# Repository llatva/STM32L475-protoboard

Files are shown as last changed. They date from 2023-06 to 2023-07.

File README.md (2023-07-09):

## STM32L475 protoboard

Development board for STM32L475 (4-layer board). Includes header for W5500 Ethernet module (SPI bus).

JP2 solder jumper needs to be short-circuited to enable USB VBUS detection (not needed if powered only from microUSB connector). Solder jumper needs to be short-circuited to enable USR1 LED. R8 is NOT to be mounted (USB data line pull-up is not used for this MCU type). Fuse pads are for polyswitch fuses. SMD capacitor pads are for A/D LPF (MCU pins have multiple functions).

Boot selection pin (BOOT0) next to the programming connector should be in normal operation shorted to GND (jumper). This means booting from FLASH.

Connector pinouts are documented on the bottom side of the board (programming interface, SPI interface).

See also the daughterboard, in the subdirectory "STM32daughter".

Designed by Lasse OH3HZB 2023

This work is licensed under a [Creative Commons Attribution-NonCommercial 4.0 International License (CC BY-NC 4.0)](https://creativecommons.org/licenses/by-nc/4.0/).

### RevA ERRATA

* Silkscreen: BOTTOM silkscreen, Ethernet connector's pin next to 3V3 is VDC, not "NC". Actual wiring is correct.

### 3D

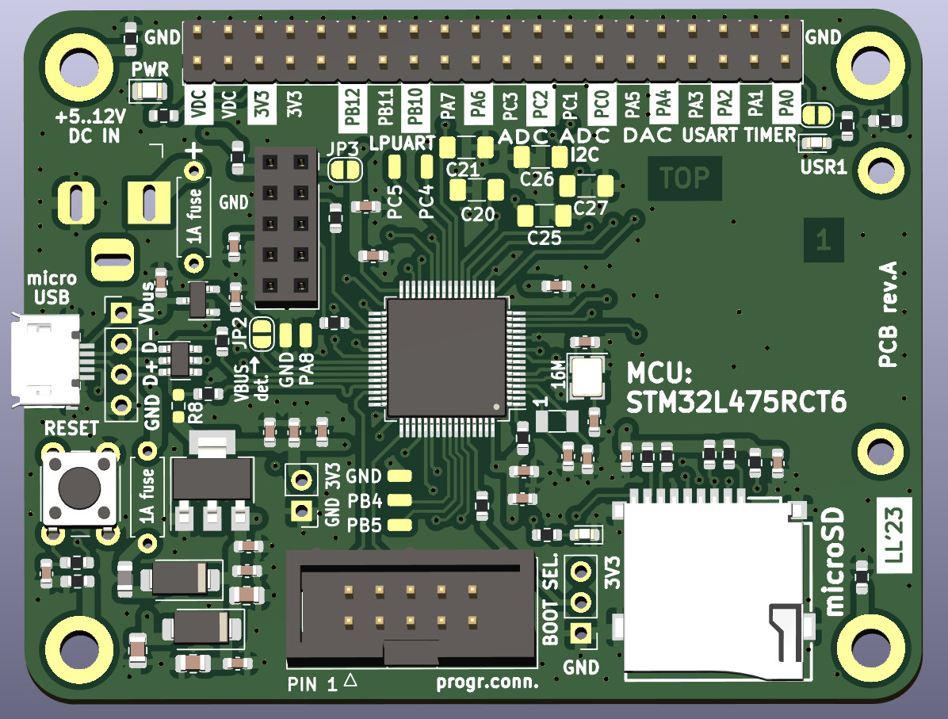
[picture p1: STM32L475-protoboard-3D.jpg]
3d


### Photo

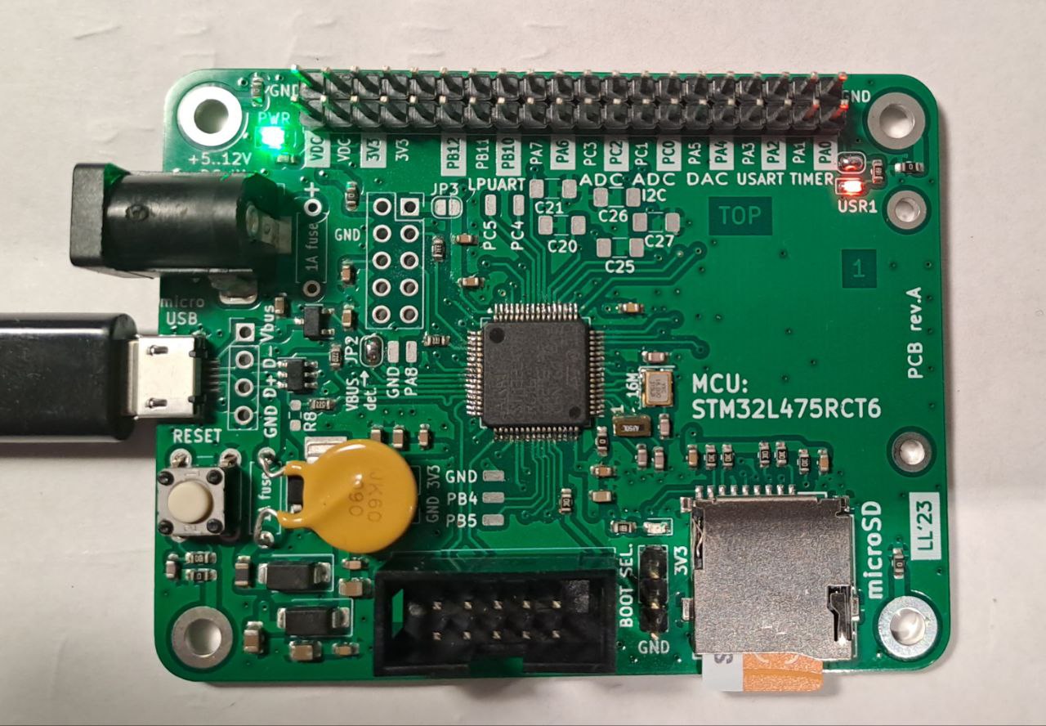
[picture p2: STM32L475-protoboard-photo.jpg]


### Schematic

Open with KiCAD (v.7+) or use [this PDF](STM32L475-protoboard.pdf).

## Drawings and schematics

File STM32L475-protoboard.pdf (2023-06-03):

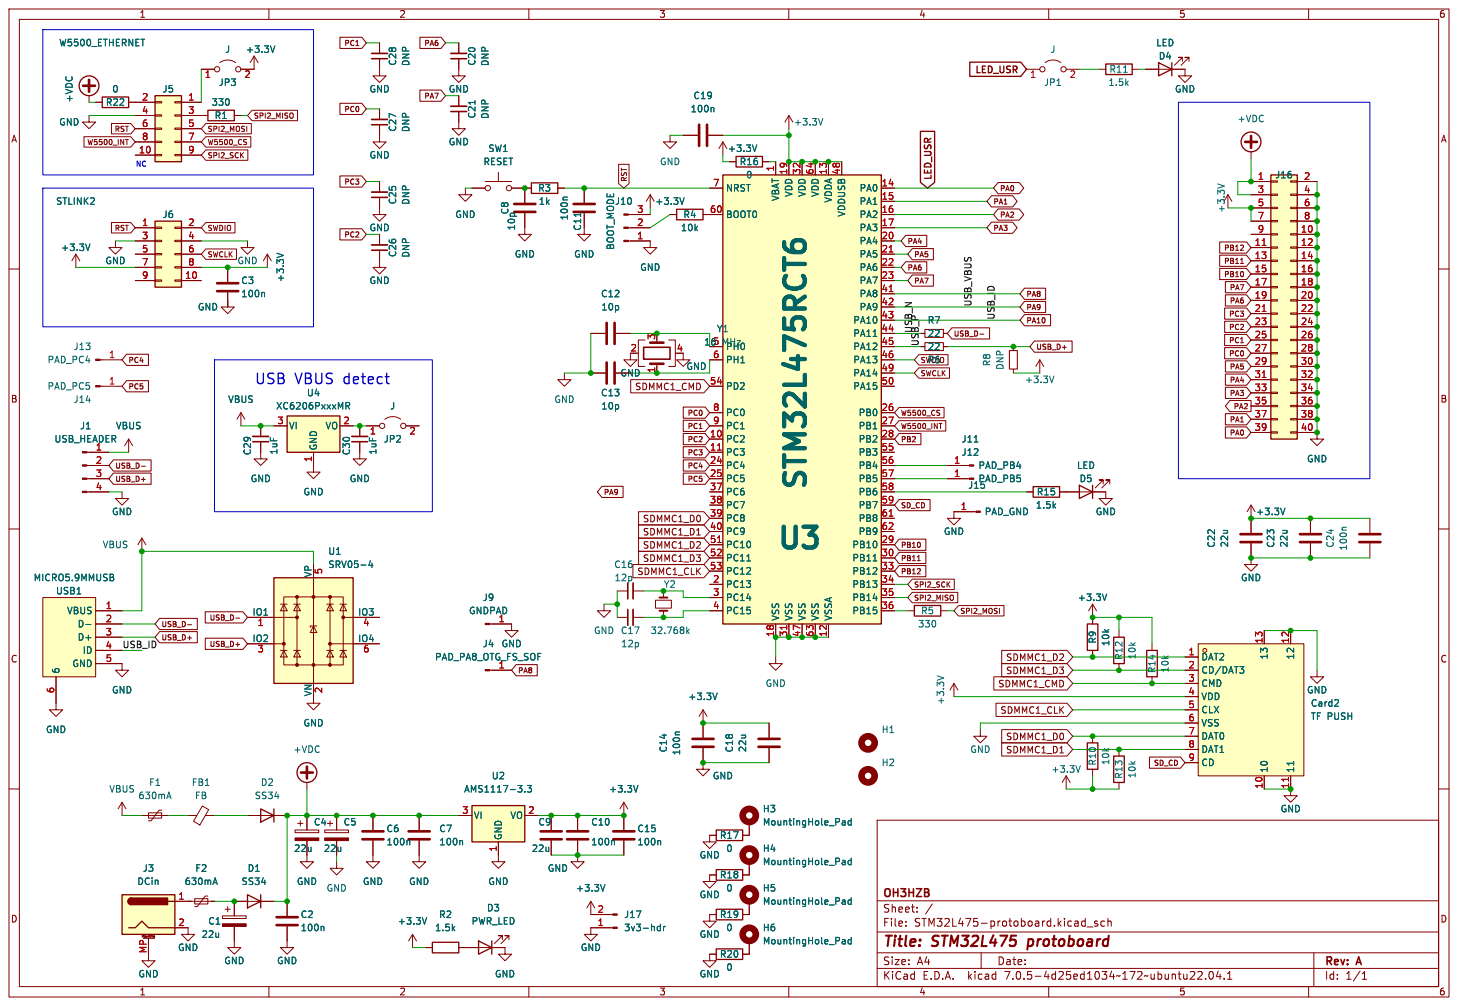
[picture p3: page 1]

1 PC2 10 PC3 11 VSSA 12 VDDA 13 PA0 14 PA1 15 PA2 16 PA3 17 VSS 18 VDD 19 PC13 2 PA4 20 PA5 21 PA6 22 PA7 23 PC4 24 PC5 25 PB0 26 PB1 27 PB2 28 PB10 29 PC14 3 PB11 30 VSS 31 VDD 32 PB12 33 PB13 34 PB14 35 PB15 36 PC6 37 PC7 38 PC8 39 PC15 4 PC9 40 PA8 41 PA9 42 PA10 43 PA11 44 PA12 45 PA13 46 VSS 47 VDDUSB 48 PA14 49 PH0 5 PA15 50 PC10 51 PC11 52 PC12 53 PD2 54 PB3 55 PB4 56 PB5 57 PB6 58 PB7 59 PH1 6 BOOT0 60 PB8 61 PB9 62 VSS 63 VDD 64 NRST 7 PC0 8 PC1 9 U3STM32L475RCT6 C13

1 PC2 10 PC3 11 VSSA 12 VDDA 13 PA0 14 PA1 15 PA2 16 PA3 17 VSS 18 VDD 19 PC13 2 PA4 20 PA5 21 PA6 22 PA7 23 PC4 24 PC5 25 PB0 26 PB1 27 PB2 28 PB10 29 PC14 3 PB11 30 VSS 31 VDD 32 PB12 33 PB13 34 PB14 35 PB15 36 PC6 37 PC7 38 PC8 39 PC15 4 PC9 40 PA8 41 PA9 42 PA10 43 PA11 44 PA12 45 PA13 46 VSS 47 VDDUSB 48 PA14 49 PH0 5 PA15 50 PC10 51 PC11 52 PC12 53 PD2 54 PB3 55 PB4 56 PB5 57 PB6 58 PB7 59 PH1 6 BOOT0 60 PB8 61 PB9 62 VSS 63 VDD 64 NRST 7 PC0 8 PC1 9 C13

FB1 FB VBUS GND GND

1 VO 2 VI 3 U2 AMS1117-3.3 GND GND

1 VO 2 VI 3 GND GND

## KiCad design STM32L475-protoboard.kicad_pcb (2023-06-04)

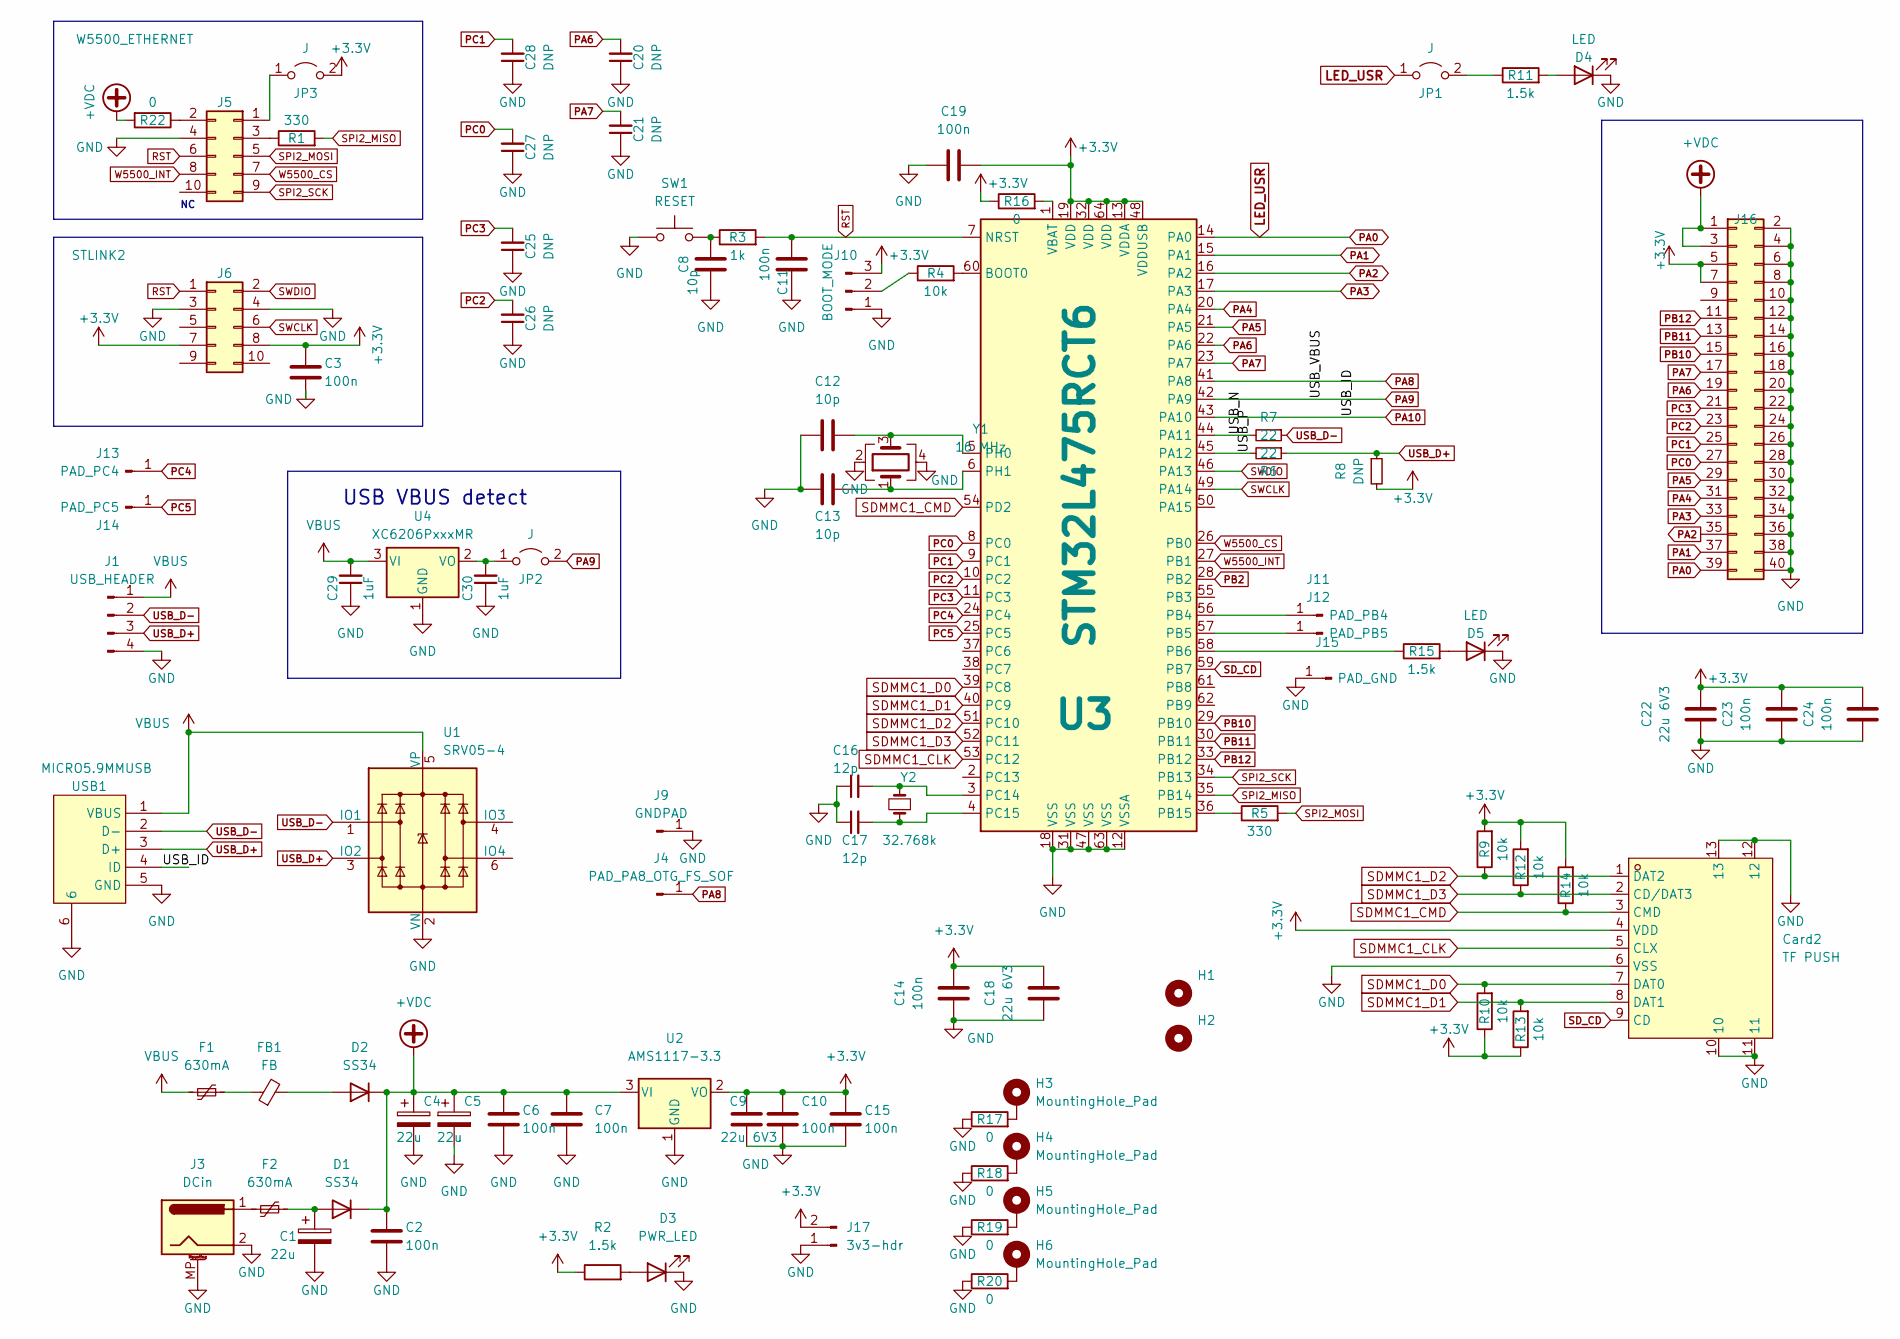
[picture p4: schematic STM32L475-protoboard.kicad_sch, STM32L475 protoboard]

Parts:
C1, C4, C5: 22u; C_0805_2012Metric; LCSC C45783
C2, C3, C6, C7, C10, C11, C14, C15, C19, C23, C24: 100n; C_0603_1608Metric; LCSC C14663
C8, C12, C13: 10p; C_0603_1608Metric; LCSC C1634
C9, C18, C22: 22u 6V3; C_0603_1608Metric; LCSC C59461
C16, C17: 12p; C_0603_1608Metric; LCSC C38523
C20, C21, C25, C26, C27, C28: DNP; C_1206_3216Metric_Pad1.33x1.80mm_HandSolder
C29, C30: 1uF; C_0603_1608Metric; LCSC C15849
Card2: TF PUSH; TF-SMD_TF-PUSH; LCSC Part C393941
D1, D2: SS34; D_SMA; LCSC C8678
D3: PWR_LED; LED_0805_2012Metric; LCSC C2297
D4, D5: LED; LED_0603_1608Metric; LCSC C2286
F1, F2: 630mA; R_Axial_DIN0207_L6.3mm_D2.5mm_P7.62mm_Horizontal
FB1: FB; L_0805_2012Metric; LCSC C1015
H1, H2: MountingHole_Pad; MountingHole_2.2mm_M2_DIN965_Pad_TopBottom
H3, H4, H5, H6: MountingHole_Pad; MountingHole_3.2mm_M3_DIN965_Pad_TopBottom
J1: USB_HEADER; PinHeader_1x04_P2.54mm_Vertical
J3: DCin; BarrelJack_Horizontal
J4: PAD_PA8_OTG_FS_SOF; SolderWirePad_1x01_SMD_1x2mm
J5: W5500_ETHERNET; PinSocket_2x05_P2.54mm_Vertical
J6: STLINK2; IDC-Header_2x05_P2.54mm_Vertical
J9: GNDPAD; SolderWirePad_1x01_SMD_1x2mm
J10: BOOT_MODE; PinHeader_1x03_P2.54mm_Vertical
J11: PAD_PB4; SolderWirePad_1x01_SMD_1x2mm
J12: PAD_PB5; SolderWirePad_1x01_SMD_1x2mm
J13: PAD_PC4; SolderWirePad_1x01_SMD_1x2mm
J14: PAD_PC5; SolderWirePad_1x01_SMD_1x2mm
J15: PAD_GND; SolderWirePad_1x01_SMD_1x2mm
J16: Conn_02x20_Odd_Even; PinHeader_2x20_P2.54mm_Vertical
J17: 3v3-hdr; PinHeader_1x02_P2.54mm_Vertical
JP1, JP2, JP3: J; SolderJumper-2_P1.3mm_Open_RoundedPad1.0x1.5mm
R1, R5: 330; R_0603_1608Metric; LCSC C23138
R2, R11, R15: 1.5k; R_0603_1608Metric; LCSC C22843
R3: 1k; R_0603_1608Metric_Pad0.98x0.95mm_HandSolder; LCSC C21190
R4, R9, R10, R12, R13, R14: 10k; R_0603_1608Metric; LCSC C25804
R6, R7: 22; R_0603_1608Metric; LCSC C23345
R8: DNP; R_0603_1608Metric_Pad0.98x0.95mm_HandSolder
R16, R17, R18, R19, R20, R22: 0; R_0603_1608Metric_Pad0.98x0.95mm_HandSolder; LCSC C21189
SW1: RESET; SW_PUSH_6mm_H4.3mm
U1: SRV05-4; SOT-23-6; LCSC C85364
U2: AMS1117-3.3; SOT-223-3_TabPin2; LCSC C6186
U3: STM32L475RCT6; LQFP-64_10x10mm_P0.5mm
U4: XC6206PxxxMR; SOT-23-3; LCSC C5446
USB1: MICRO5.9MMUSB; MICRO-USB-SMD_5P-P0.65-H-F_MICRO5.9MMUSB; LCSC C393940
Y1: 16 MHz; Crystal_SMD_3225-4Pin_3.2x2.5mm; LCSC C13738
Y2: 32.768k; Crystal_SMD_3215-2Pin_3.2x1.5mm; LCSC C32346

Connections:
+3V3: C3.1, C9.1, C10.1, C14.2, C15.1, C18.2, C19.2, C22.2, C23.2, C24.2, Card2.4 (VDD), J6.7, J6.8, J10.3, J16.5, J16.7, J17.2, JP3.2 (B), R2.1, R8.2, R9.2, R10.1, R12.2, R13.1, R14.2, R16.1, U2.2 (VO), U3.13 (VDDA), U3.19 (VDD), U3.32 (VDD), U3.48 (VDDUSB), U3.64 (VDD)
+VDC: C2.1, C4.1, C5.1, C6.1, C7.1, D1.1 (K), D2.1 (K), J16.1, J16.3, R22.2, U2.3 (VI)
/USB_N: R6.2, U3.44 (PA11)
/USB_P: R7.2, U3.45 (PA12)
GND: C1.2, C2.2, C3.2, C4.2, C5.2, C6.2, C7.2, C8.2, C9.2, C10.2, C11.1, C12.1, C13.2, C14.1, C15.2, C16.1, C17.1, C18.1, C19.1, C20.1, C21.1, C22.1, C23.1, C24.1, C25.1, C26.1, C27.1, C28.1, C29.1, C30.1, Card2.6 (VSS), Card2.10, Card2.11, Card2.12, Card2.13, D3.1 (K), D4.1 (K), D5.1 (K), J1.4, J3.2, J3.MP (MountPin), J5.4, J6.3, J6.4, J9.1, J10.1, J15.1, J16.2, J16.4, J16.6, J16.8, J16.10, J16.12, J16.14, J16.16, J16.18, J16.20, J16.22, J16.24, J16.26, J16.28, J16.30, J16.32, J16.34, J16.36, J16.38, J16.40, J17.1, R17.1, R18.1, R19.1, R20.1, SW1.1, U1.2 (VN), U2.1 (GND), U3.12 (VSSA), U3.18 (VSS), U3.31 (VSS), U3.47 (VSS), U3.63 (VSS), U4.1 (GND), USB1.5 (GND), USB1.6, Y1.2, Y1.4
LED_USR: J16.39, JP1.1 (A), U3.14 (PA0)
unnamed: C8.1, R3.1, SW1.2
unnamed: C1.1, D1.2 (A), F2.1
unnamed: D2.2 (A), FB1.2
unnamed: D3.2 (A), R2.2
unnamed: D4.2 (A), R11.2
unnamed: D5.2 (A), R15.2
unnamed: F1.1, FB1.1
unnamed: F2.2, J3.1
unnamed: H3.1, R17.2
unnamed: H4.1, R18.2
unnamed: H5.1, R19.2
unnamed: H6.1, R20.2
unnamed: J5.1, JP3.1 (A)
unnamed: J5.2, R22.1
unnamed: J5.3, R1.1
unnamed: J10.2, R4.1
unnamed: J11.1, U3.56 (PB4)
unnamed: J12.1, U3.57 (PB5)
unnamed: JP1.2 (B), R11.1
unnamed: C30.2, JP2.1 (A), U4.2 (VO)
unnamed: R4.2, U3.60 (BOOT0)
unnamed: R15.1, U3.58 (PB6)
unnamed: R5.1, U3.36 (PB15)
unnamed: C16.2, U3.3 (PC14), Y2.2
unnamed: C17.2, U3.4 (PC15), Y2.1
unnamed: C12.2, U3.5 (PH0), Y1.3
unnamed: C13.1, U3.6 (PH1), Y1.1
unnamed: R16.2, U3.1 (VBAT)
PA1: J16.37, U3.15 (PA1)
PA2: J16.35, U3.16 (PA2)
PA3: J16.33, U3.17 (PA3)
PA4: J16.31, U3.20 (PA4)
PA5: J16.29, U3.21 (PA5)
PA6: C20.2, J16.19, U3.22 (PA6)
PA7: C21.2, J16.17, U3.23 (PA7)
PA8: J4.1, U3.41 (PA8)
PA9: JP2.2 (B), U3.42 (PA9)
PA10: U3.43 (PA10), USB1.4 (ID)
PB2: U3.28 (PB2)
PB10: J16.15, U3.29 (PB10)
PB11: J16.13, U3.30 (PB11)
PB12: J16.11, U3.33 (PB12)
PC0: C27.2, J16.27, U3.8 (PC0)
PC1: C28.2, J16.25, U3.9 (PC1)
PC2: C26.2, J16.23, U3.10 (PC2)
PC3: C25.2, J16.21, U3.11 (PC3)
PC4: J13.1, U3.24 (PC4)
PC5: J14.1, U3.25 (PC5)
RST: C11.2, J5.6, J6.1, R3.2, U3.7 (NRST)
SDMMC1_CLK: Card2.5 (CLX), U3.53 (PC12)
SDMMC1_CMD: Card2.3 (CMD), R14.1, U3.54 (PD2)
SDMMC1_D0: Card2.7 (DAT0), R10.2, U3.39 (PC8)
SDMMC1_D1: Card2.8 (DAT1), R13.2, U3.40 (PC9)
SDMMC1_D2: Card2.1 (DAT2), R9.1, U3.51 (PC10)
SDMMC1_D3: Card2.2 (CD/DAT3), R12.1, U3.52 (PC11)
SD_CD: Card2.9 (CD), U3.59 (PB7)
SPI2_MISO: R1.2, U3.35 (PB14)
SPI2_MOSI: J5.5, R5.2
SPI2_SCK: J5.9, U3.34 (PB13)
SWCLK: J6.6, U3.49 (PA14)
SWDIO: J6.2, U3.46 (PA13)
USB_D+: J1.3, R7.1, R8.1, U1.3 (IO2), USB1.3 (D+)
USB_D-: J1.2, R6.1, U1.1 (IO1), USB1.2 (D-)
VBUS: C29.2, F1.2, J1.1, U1.5 (VP), U4.3 (VI), USB1.1 (VBUS)
W5500_CS: J5.7, U3.26 (PB0)
W5500_INT: J5.8, U3.27 (PB1)

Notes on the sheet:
USB VBUS detect

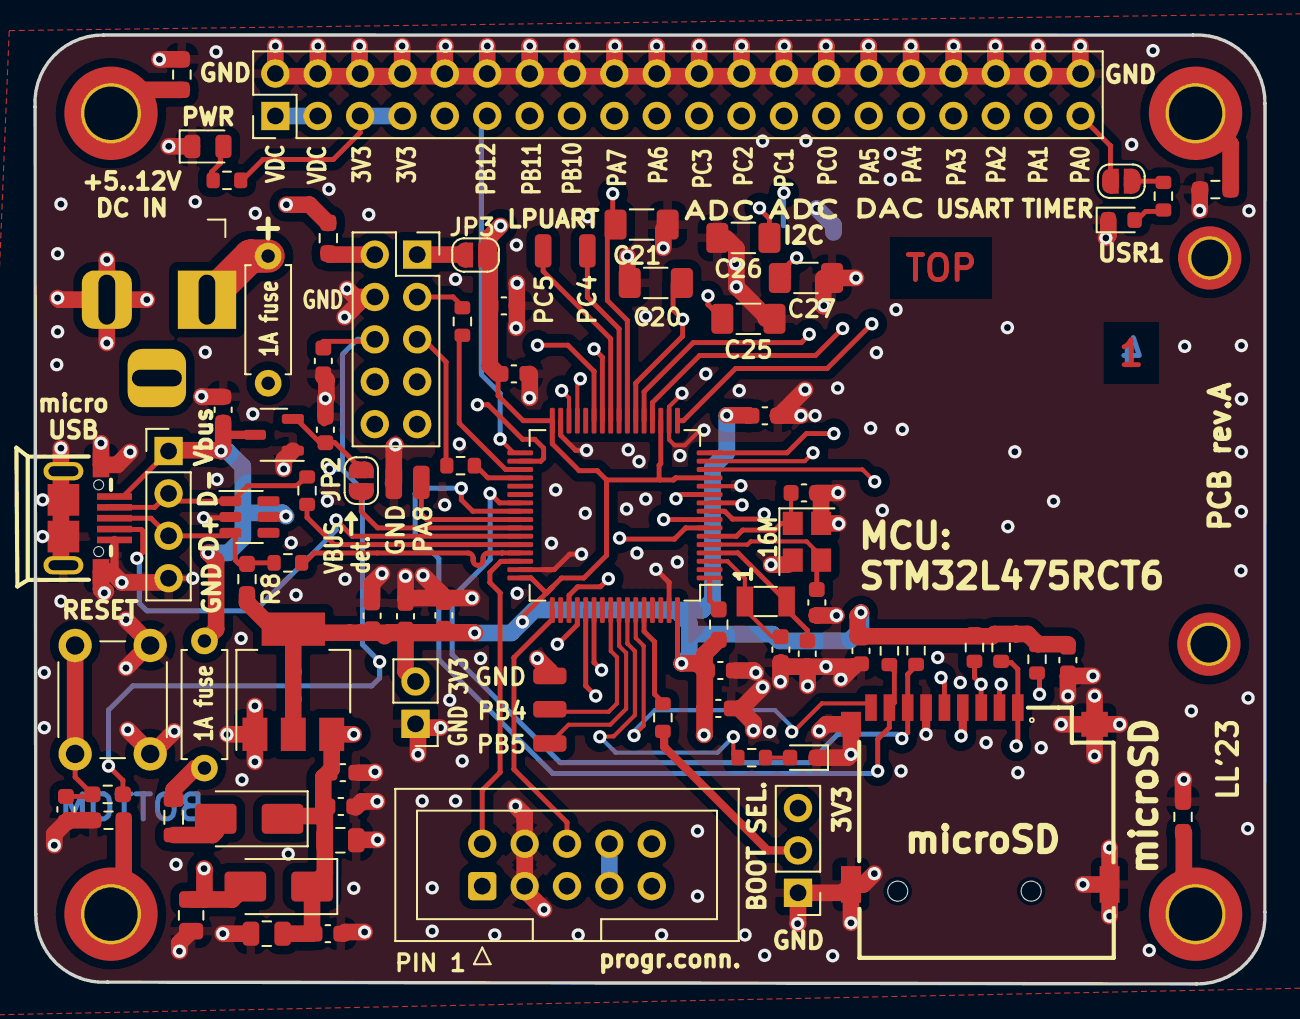
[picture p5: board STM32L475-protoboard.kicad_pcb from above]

Board: 4 copper layers, 73.7 x 56.9 mm, 91 parts (1 on the bottom side), 71 nets.

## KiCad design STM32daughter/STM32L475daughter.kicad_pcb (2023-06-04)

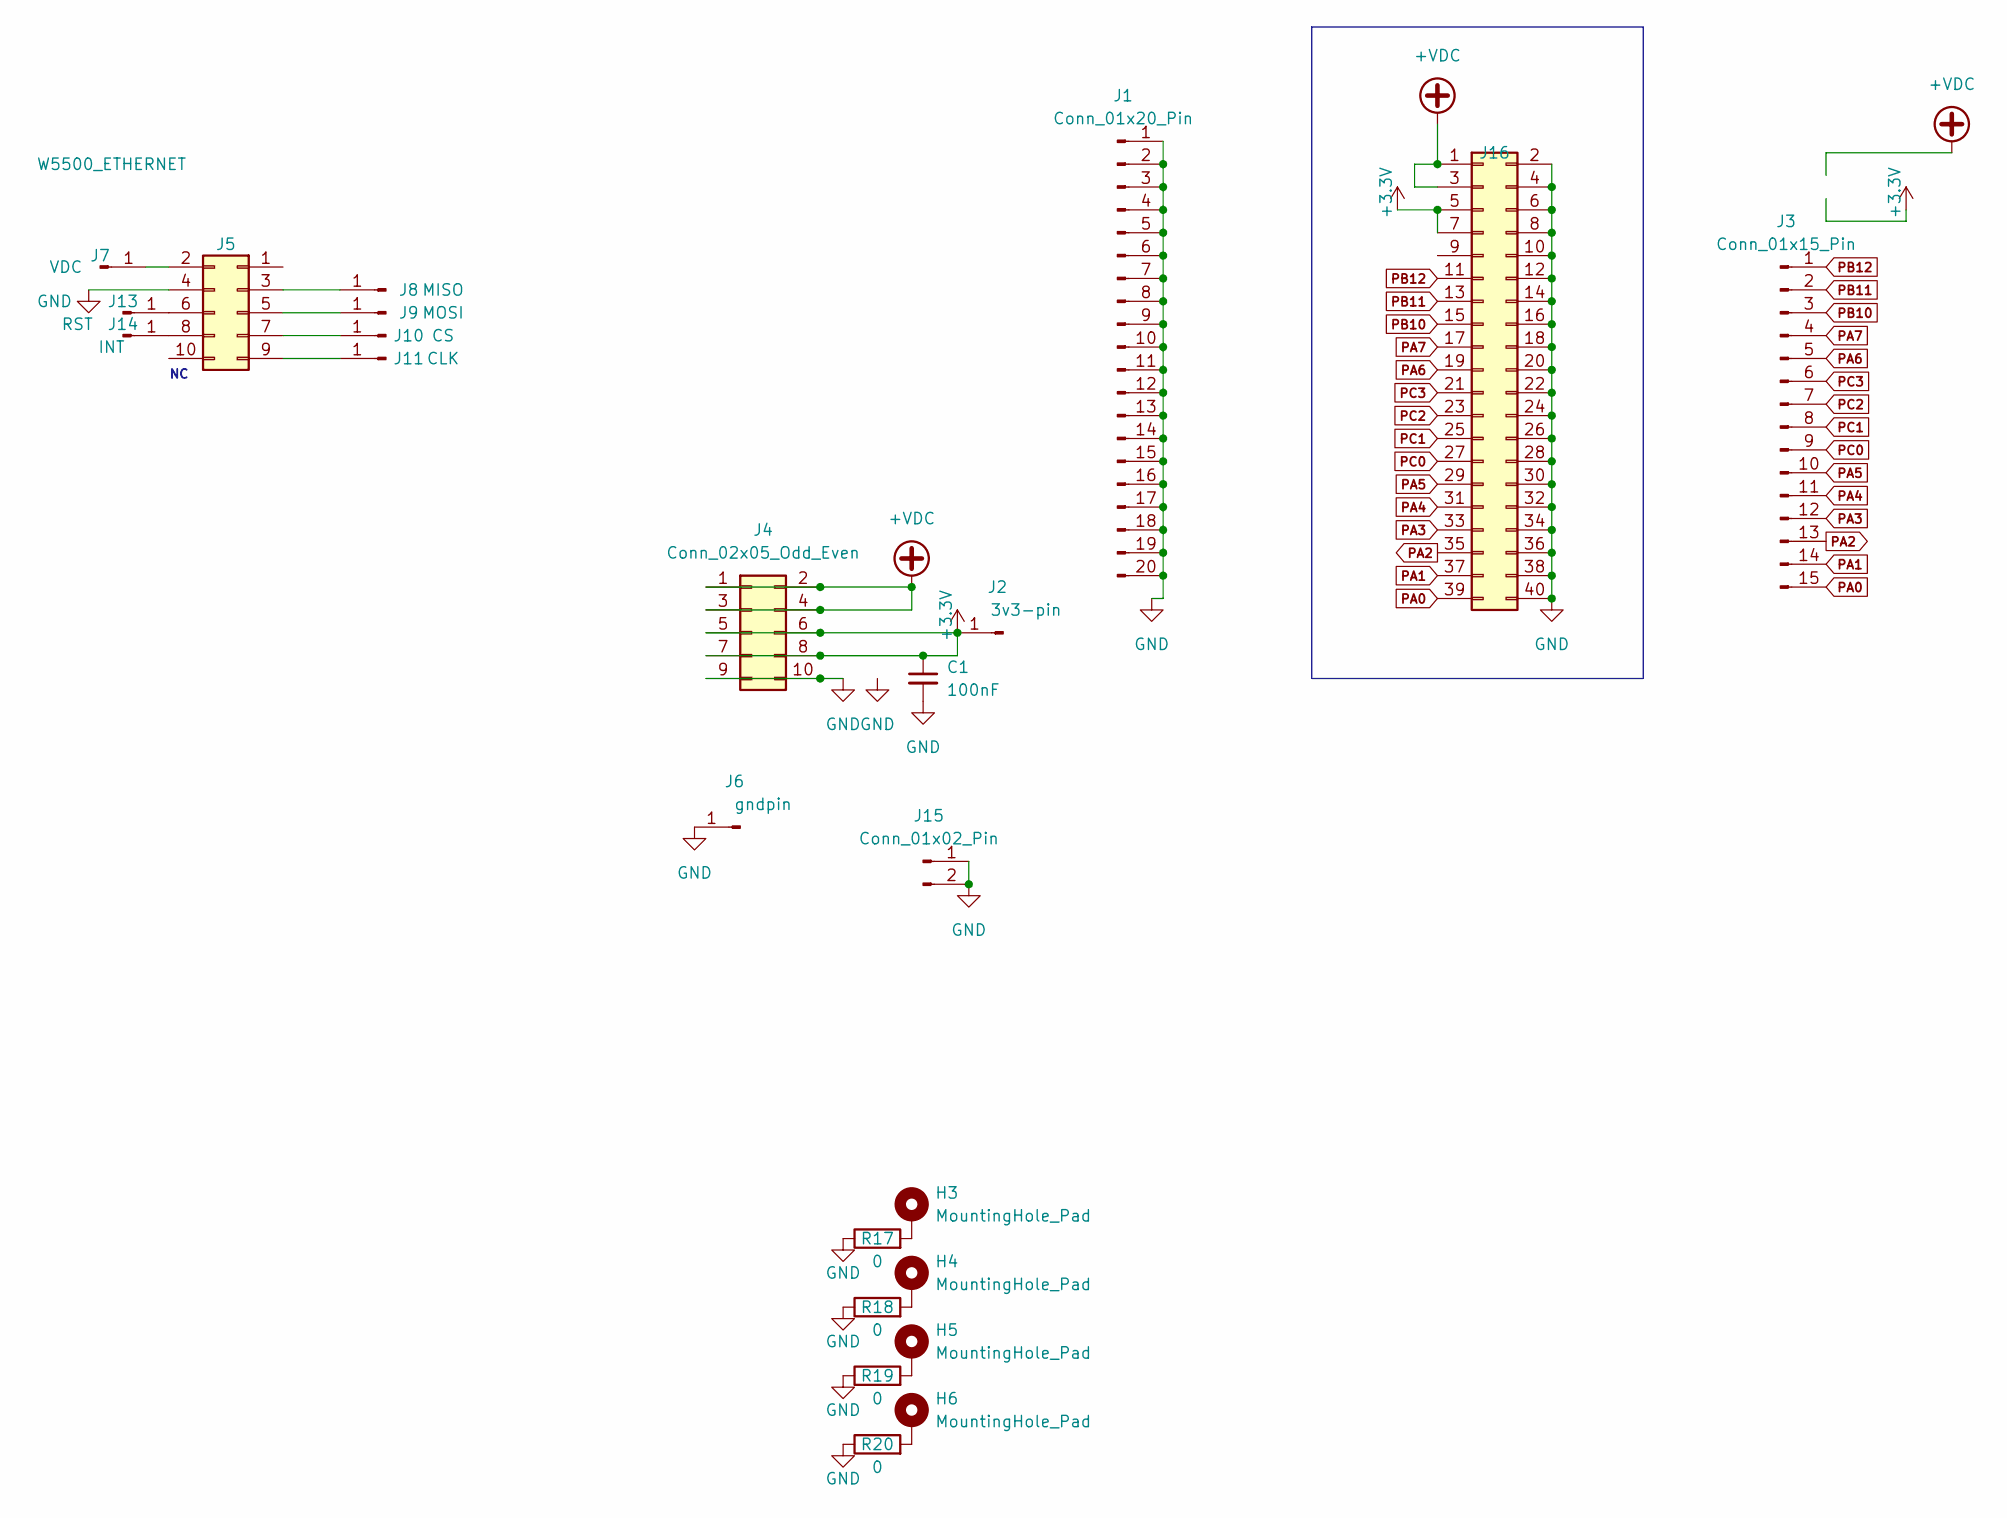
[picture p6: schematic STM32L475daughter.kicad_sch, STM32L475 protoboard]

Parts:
C1: 100nF; C_1206_3216Metric_Pad1.33x1.80mm_HandSolder
H3, H4, H5, H6: MountingHole_Pad; MountingHole_3.2mm_M3_DIN965_Pad_TopBottom
J1: Conn_01x20_Pin; PinHeader_1x20_P2.54mm_Vertical
J2: 3v3-pin; SolderWirePad_1x01_SMD_1x2mm
J3: Conn_01x15_Pin; PinHeader_1x15_P2.54mm_Vertical
J4: Conn_02x05_Odd_Even; PinHeader_2x05_P2.54mm_Vertical
J5: W5500_ETHERNET; PinSocket_2x05_P2.54mm_Vertical
J6: gndpin; SolderWirePad_1x01_SMD_1x2mm
J7: VDC; SolderWirePad_1x01_SMD_1x2mm
J8: MISO; SolderWirePad_1x01_SMD_1x2mm
J9: MOSI; SolderWirePad_1x01_SMD_1x2mm
J10: CS; SolderWirePad_1x01_SMD_1x2mm
J11: CLK; SolderWirePad_1x01_SMD_1x2mm
J13: RST; SolderWirePad_1x01_SMD_1x2mm
J14: INT; SolderWirePad_1x01_SMD_1x2mm
J15: Conn_01x02_Pin; PinHeader_1x02_P2.54mm_Vertical
J16: Conn_02x20_Odd_Even; PinHeader_2x20_P2.54mm_Vertical
R17, R18, R19, R20: 0; R_0603_1608Metric_Pad0.98x0.95mm_HandSolder; LCSC C21189

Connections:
+3V3: C1.1, J2.1, J4.5, J4.6, J4.7, J4.8, J16.5, J16.7
+VDC: J4.1, J4.2, J4.3, J4.4, J16.1, J16.3
GND: C1.2, J1.1, J1.2, J1.3, J1.4, J1.5, J1.6, J1.7, J1.8, J1.9, J1.10, J1.11, J1.12, J1.13, J1.14, J1.15, J1.16, J1.17, J1.18, J1.19, J1.20, J4.9, J4.10, J5.4, J6.1, J15.1, J15.2, J16.2, J16.4, J16.6, J16.8, J16.10, J16.12, J16.14, J16.16, J16.18, J16.20, J16.22, J16.24, J16.26, J16.28, J16.30, J16.32, J16.34, J16.36, J16.38, J16.40, R17.1, R18.1, R19.1, R20.1
unnamed: H3.1, R17.2
unnamed: H4.1, R18.2
unnamed: H5.1, R19.2
unnamed: H6.1, R20.2
unnamed: J5.2, J7.1
unnamed: J5.3, J8.1
unnamed: J5.5, J9.1
unnamed: J5.7, J10.1
unnamed: J5.9, J11.1
unnamed: J5.6, J13.1
unnamed: J5.8, J14.1
PA0: J3.15, J16.39
PA1: J3.14, J16.37
PA2: J3.13, J16.35
PA3: J3.12, J16.33
PA4: J3.11, J16.31
PA5: J3.10, J16.29
PA6: J3.5, J16.19
PA7: J3.4, J16.17
PB10: J3.3, J16.15
PB11: J3.2, J16.13
PB12: J3.1, J16.11
PC0: J3.9, J16.27
PC1: J3.8, J16.25
PC2: J3.7, J16.23
PC3: J3.6, J16.21

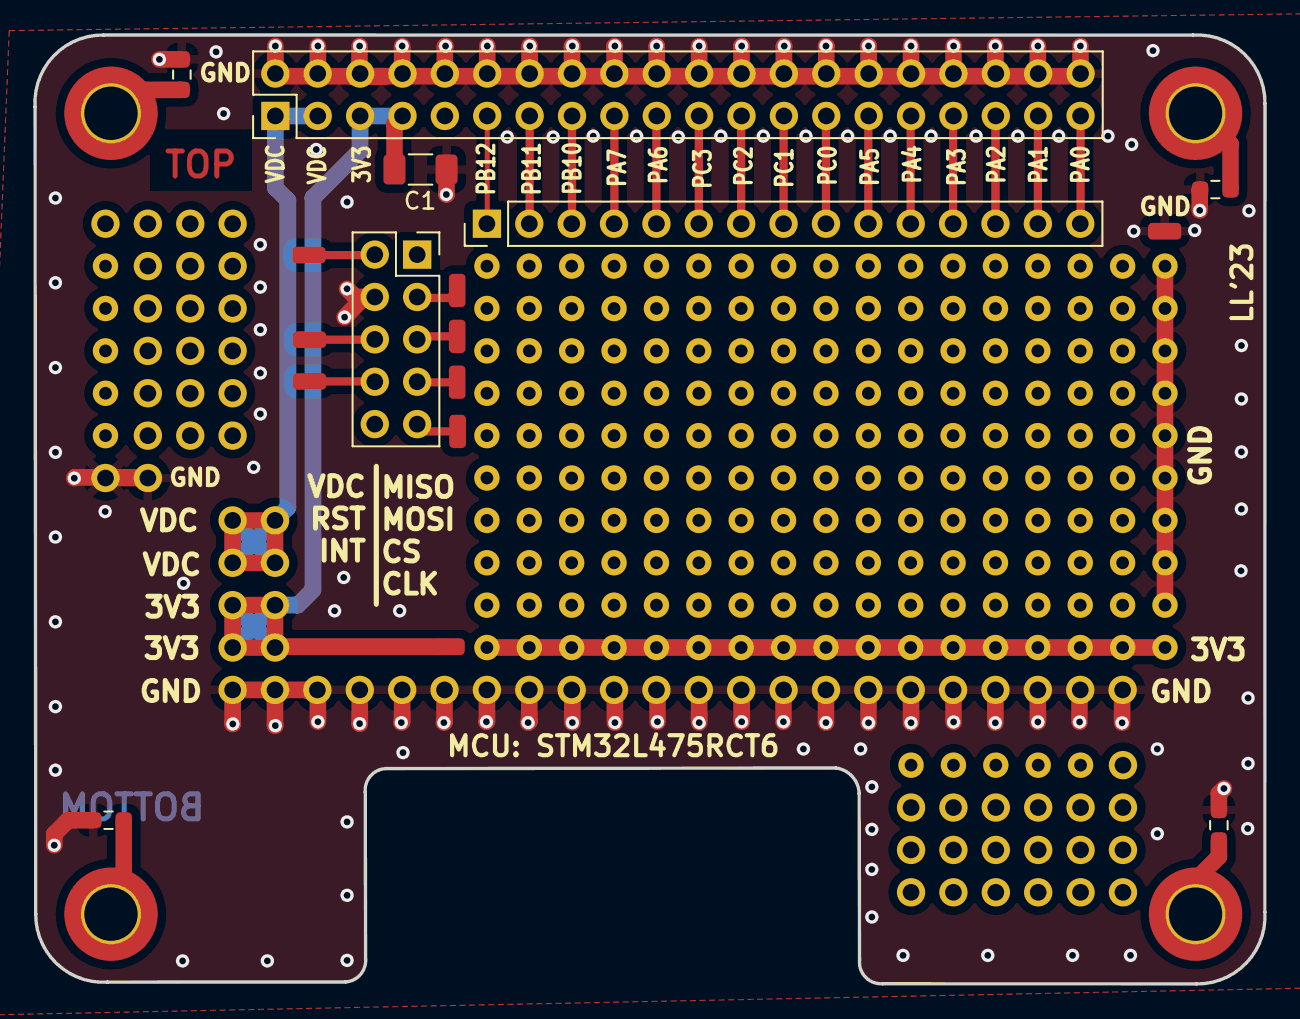
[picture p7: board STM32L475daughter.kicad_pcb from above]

Board: 2 copper layers, 73.7 x 56.9 mm, 24 parts (0 on the bottom side), 29 nets.

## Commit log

2023-05-14 initial commit to github
    [STM32L475-protoboard.kicad_sch]
2023-05-15 some progress
    [STM32L475-protoboard.kicad_sch]
2023-05-19 littlebit further
    [STM32L475-protoboard.kicad_pcb, STM32L475-protoboard.kicad_sch]
2023-05-19 final commit for this session, to be continued
    [STM32L475-protoboard.kicad_pcb, STM32L475-protoboard.kicad_sch]
2023-05-22 some notes to schema
    [STM32L475-protoboard.kicad_sch]
2023-05-24 saveä
    [STM32L475-protoboard.kicad_pcb, STM32L475-protoboard.kicad_sch]
2023-05-24 STM32L475 should have internal pullup for USB line, but need to be checked (now DNP resistor)
    [STM32L475-protoboard.kicad_pcb, STM32L475-protoboard.kicad_sch]
2023-05-24 todo update
    [STM32L475-protoboard.kicad_sch]
2023-05-24 some fixes
    [STM32L475-protoboard.kicad_pcb, STM32L475-protoboard.kicad_sch]
2023-05-25 some routing
    [STM32L475-protoboard.kicad_pcb, STM32L475-protoboard.kicad_sch]
2023-05-25 some more pins
    [STM32L475-protoboard.kicad_pcb, STM32L475-protoboard.kicad_sch]
2023-05-25 SD -> microSD, w.i.p
    [STM32L475-protoboard.kicad_pcb, STM32L475-protoboard.kicad_sch]
2023-05-25 todo: find proper microSD connector from JLC
    [STM32L475-protoboard.kicad_pcb, STM32L475-protoboard.kicad_sch]
2023-05-29 moved mcu a littlebit left
    [STM32L475-protoboard.kicad_pcb, STM32L475-protoboard.kicad_sch]
2023-05-30 migration to KiCAD7
    [STM32L475-protoboard.kicad_pcb, STM32L475-protoboard.kicad_sch]
2023-05-30 microsd + misc
    [STM32L475-protoboard.kicad_pcb, STM32L475-protoboard.kicad_sch]
2023-05-30 to be continued next time
    [STM32L475-protoboard.kicad_pcb, STM32L475-protoboard.kicad_sch]
2023-06-01 misc routing
    [STM32L475-protoboard.kicad_pcb, STM32L475-protoboard.kicad_sch]
2023-06-01 to be continued
    [STM32L475-protoboard.kicad_pcb, STM32L475-protoboard.kicad_sch]
2023-06-02 almost there
    [STM32L475-protoboard.kicad_pcb, STM32L475-protoboard.kicad_sch]
2023-06-02 hole placement still to be fixed, leaving measurements visible
    [STM32L475-protoboard.kicad_pcb]
2023-06-02 fixed silk placement on bottom, long header
    [STM32L475-protoboard.kicad_pcb]
2023-06-03 mounting holes
    [STM32L475-protoboard.kicad_pcb, STM32L475-protoboard.kicad_sch]
2023-06-03 drc trace separtion checking
    [STM32L475-protoboard.kicad_pcb, STM32L475-protoboard.kicad_sch]
2023-06-03 micro usb connector change
    [STM32L475-protoboard.kicad_pcb, STM32L475-protoboard.kicad_sch]
2023-06-03 forgotted microUSB files + silk modifications to pcb
    [STM32L475-protoboard.kicad_pcb]
2023-06-03 schema pdf
    [STM32L475-protoboard.kicad_sch]
2023-06-03 plot directory, schema printout
2023-06-03 minor fixes
    [STM32L475-protoboard.kicad_pcb]
2023-06-03 adjusted corners a littlebit
    [STM32L475-protoboard.kicad_pcb]
2023-06-03 fixed a couple of DRC errors
    [STM32L475-protoboard.kicad_pcb, STM32L475-protoboard.kicad_sch]
2023-06-03 lcsc code fixes
    [STM32L475-protoboard.kicad_pcb, STM32L475-protoboard.kicad_sch]
